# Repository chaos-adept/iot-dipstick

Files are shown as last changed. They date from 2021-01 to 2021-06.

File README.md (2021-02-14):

# IoT Dipstick
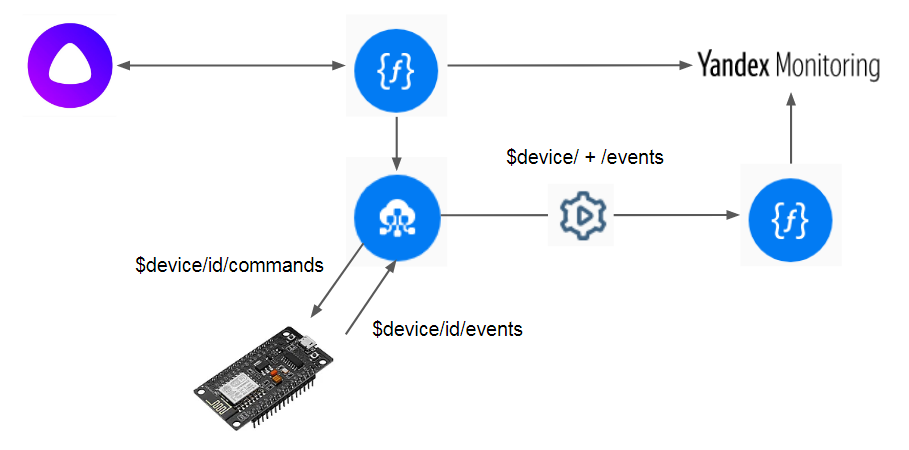
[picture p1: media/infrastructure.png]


### Overview
IoT based on ESP8266 ([NodeMCU v3 board](http://www.nodemcu.com/index_cn.html)) and [Yandex Cloud](https://cloud.yandex.ru/) 
with integration with [Alice](https://yandex.ru/dev/dialogs/alice/doc/about.html)  assistant see [alice-func](terraform/cloud-functions/alice-func)

Alice configuration can't be provided in the source code, you have to configure it on your own. See references in the end of this page.

### Cloud infrastructure provisioning

note to start working with terraform you have to make a `terraform/variables_yc_account.tf`
file with actual values based on the [yandex terraform provider](https://registry.terraform.io/providers/yandex-cloud/yandex/latest/docs)

1. cd `./terraform`
1. make `variables_yc_account.tf` based on [variables_yc_account.tf.sample](terraform/variables_yc_account.tf)
1. `terraform init`
1. `terraform apply`

### Arduino firmware

the firmware is located in `arduino/air-monitor`, it is based on the [Platform IO](https://platformio.org/platformio-ide) as a replacement for Arduino IDE.

#### Initialization
1. create your yandex cloud by the terraform
1. add/modify your wi-fi settings in the `arduino/air-monitor/local_specific_variables.h` 
Once you have initialized your yandex cloud with the terraform scripts `arduino/air-monitor/local_specific_variables.h` 
#### Note
_Cloud infrastructure provisioning_ step generates `arduino/air-monitor/local_specific_variables.h` based on the   
file [arduino/air-monitor/local_specific_variables.h.sample](arduino/experements/air-monitor/local_specific_variables.h.sample)
and your environment settings, for more information see `arduino/scripts/create_local_specific_variables.sh`

### Resources to get started with the project
* [Before to Get Started](../../wiki/Before-to-Get-Started) - List of resources to get required knowledge to work with the project might be found in the wiki page
* [Prehistory and Architecture notes](../../wiki/Prehistory-and-Architecture-notes) - Prehistory of an approach might be found here
* [Alice abilities overview](https://yandex.ru/dev/dialogs/alice/doc/about.html) - Alice abilities development get startred
* [Alice based on the cloud function](https://yandex.ru/dev/dialogs/alice/doc/deploy-ycloud-function.html) - How to integrate [alice-func](terraform/cloud-functions/alice-func) into Alice ability

### IoT Dipstick Prototype
scheme
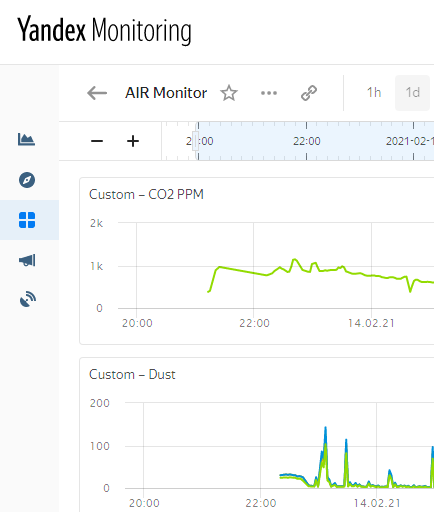
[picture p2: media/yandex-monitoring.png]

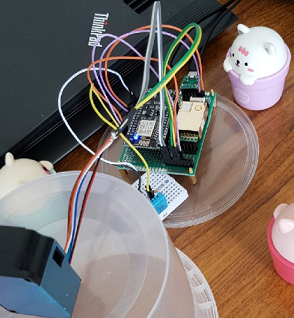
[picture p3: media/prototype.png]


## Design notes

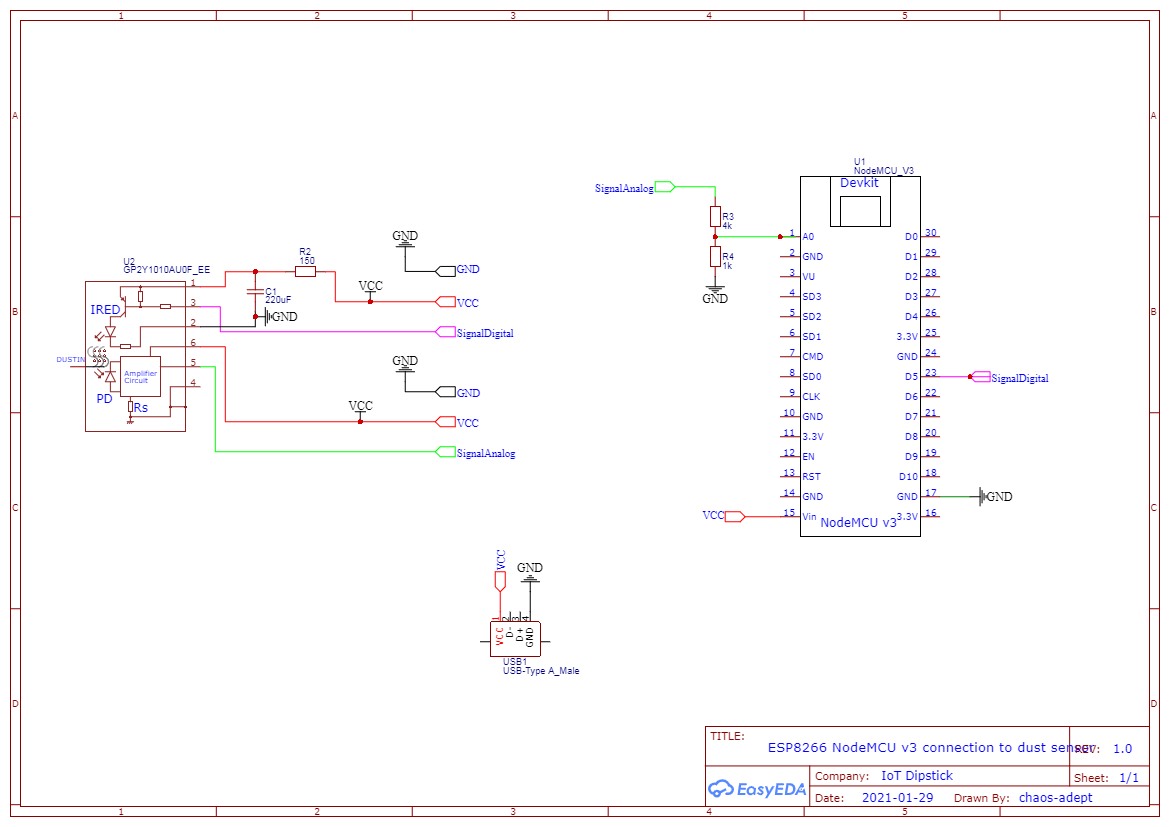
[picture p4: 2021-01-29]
arduino/experements/dust-sensor/GP2Y1010AU0F-no-lib-with-voltage-devider/Schematic_dust-sensor-and-nodemcu_2021-01-29.png

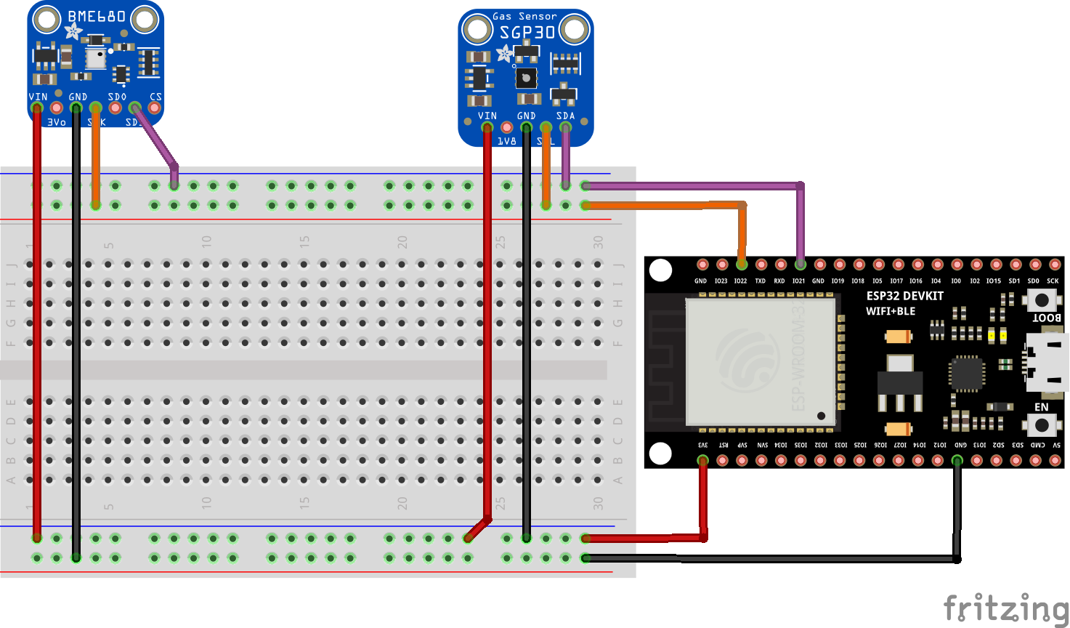
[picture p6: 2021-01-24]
arduino/experements/sensors-sgp30-bme680/fritzing/esp32-bme680-sgp30_bb.png

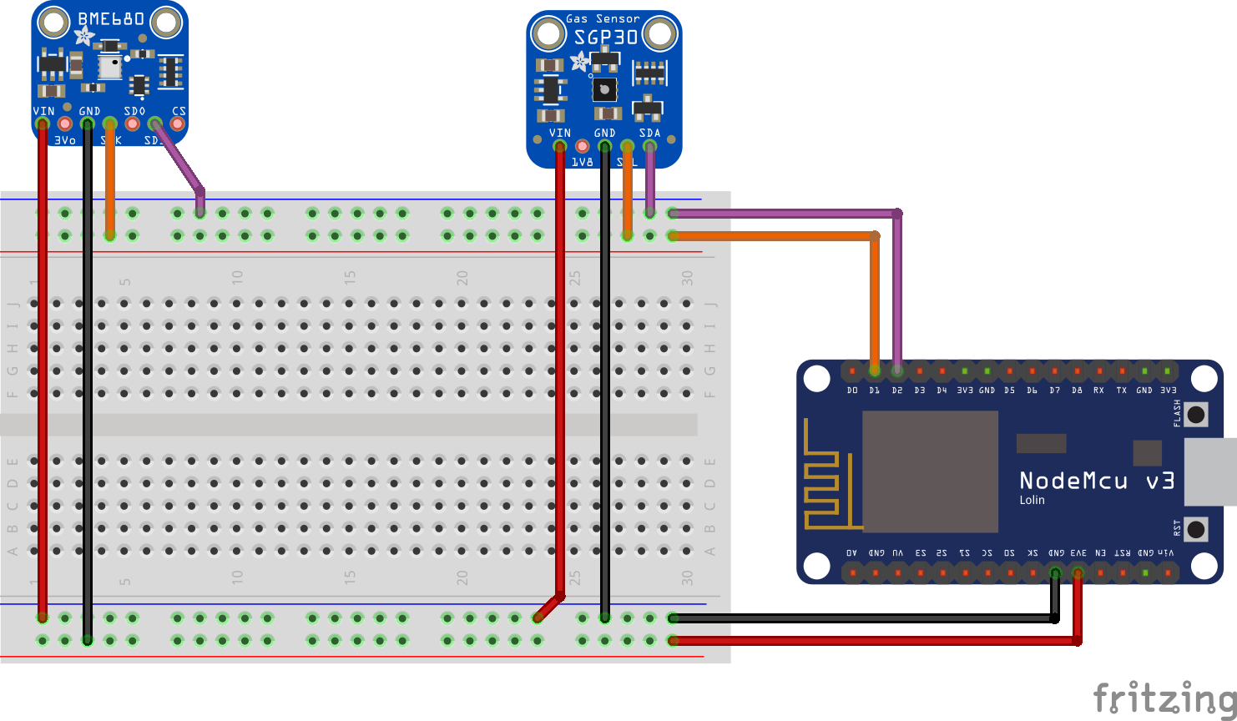
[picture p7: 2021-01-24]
arduino/experements/sensors-sgp30-bme680/fritzing/esp8266-bme680-sgp30_bb.png

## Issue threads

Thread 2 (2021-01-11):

Docs - Provide readme with get started resources

chaos-adept, 2021-01-11:
- [x] provide actual readme with list of community known resources to get started with arduino and esp8266 development
- [x] provide project specific information to get started
- [x] review and close

chaos-adept, 2021-01-13:
point #1 is resolved here
https://github.com/chaos-adept/iot-dipstick/wiki/Before-to-Get-Started

chaos-adept, 2021-01-19:
point 2 has been resolve with the provided readme in the root folder

chaos-adept, 2021-01-20:
review is required

chaos-adept, 2021-01-30:
The review has been done by working with a comrade. He doesn't use doc at all. and It is fine for me.

Closed 2021-01-30.

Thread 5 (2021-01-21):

Device - Check ESP32 as replacement for ESP8266

chaos-adept, 2021-01-21:
- [x] try to send mqtt tls messages to yandex cloud
- [ ] try to read values from dht12
- [ ] make a conditional compilation to include old wifi secure module for esp32

chaos-adept, 2021-01-23:
the result so far esp32 can be used, it was possible to configure it to send message to the cloud and read i2c sensors

chaos-adept, 2021-01-24:
there were several attempts to rewrite code to support conditions in a6ae4475bab39eb1c08531ff91cffdc1faa35624

it doesn't work under arduino ide from the scratch. it seems like an exploration of (esp-idf)[https://docs.espressif.com/projects/esp-idf/en/latest/esp32/] makes sense but it is really time-consuming

chaos-adept, 2021-01-24:
so far this issue is considered as resolved, try attempt was performed for MVP it doesn't make sense to use ESP32 because of difficulties to get started.
1. [esp-idf](https://docs.espressif.com/projects/esp-idf/en/latest/esp32/) exploration is going to be a separate task.
2. esp8266 is considered as the board for MVP

Closed 2021-01-24.

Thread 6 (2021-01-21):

Device - Assembly AIR quality sensors on the board

chaos-adept, 2021-01-21:
- [x] TVOC/eCO2 https://amperkot.ru/msk/catalog/datchik_kachestva_vozduha_v_pomeschenii_sgp30_tvoc_eco2-32614748.html
- [x] Temperature, Pressure and etc - https://amperkot.ru/msk/catalog/datchik_temperaturyi_i_vlazhnosti_bosch_cjmcu680_bme680-39166193.html
- [x] Dust hello world firmware - https://amperkot.ru/msk/catalog/datchik_pyili_sharp_gp2y1010au0f-23869558.html
- [x] Dust Sensor approach with voltage division to adopt 5v out to 1v which is supported by esp8266
- [x] Make a 5v 1a power supply with parallel connection to the esp and dust sensor
- [x] Test dust sensor with 1v out and esp8266
- [x] Integrate dust sensor in the primary firmware

chaos-adept, 2021-01-24:
1. 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
1. 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

results:
1. the first cycle of testing no real values (on esp32)
1. the next cycle of testing zero values (on esp8266, most probably damage on changing wires)

chaos-adept, 2021-01-27:
dust sensor mostly work
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

it should be connected to the esp so far it seems a voltage divider is needed
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

chaos-adept, 2021-01-28:
physical assembly with wemos d1 was successful
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

chaos-adept, 2021-01-29:
added firmware and scheme which is used for ESP8266 NodeMCU v3
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
![Uploading image.png…]()

chaos-adept, 2021-01-30:
this ticket has been resolved dht11 is used instead of dht12 which is really hard to find in the Moscow shops, the new ticket for refactoring firmware will be raised

Closed 2021-01-30.

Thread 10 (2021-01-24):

esp32 usage of esp-idf development

chaos-adept, 2021-01-24:
esp-idf - it is a framework for parallel task execution on the esp32.

this issue derives from #5  "[esp-idf](https://docs.espressif.com/projects/esp-idf/en/latest/esp32/) exploration is going to be a separate task."

it is required to adopt the following functionality under idf based:
* secured mqtt connection to the yandex cloud
* reading data from i2c sensors

chaos-adept, 2021-06-15:
so far it looks that the possible option is incremental migration by step migration to esp32 with dropping support of esp8266 with the usage of FreeRTOS and Arduino libraries + some of esp32 native functions like adc_read_raw, or touch panel

chaos-adept, 2021-06-15:
so far this task can be considered as wont fix

Closed 2021-06-15.

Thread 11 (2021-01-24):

Device - Deep Sleep Support for passive sensor only devices

chaos-adept, 2021-01-24:
Implement firmware for a sensor-only device that sends data with long intervals like 2h.
EPS has the ability to go to deep sleep, it should be used.

note the issue with sending commands to the device which sleep is out of the MVP scope

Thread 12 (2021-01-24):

Terraform - Generate system env variables and arduino header files based on the "apply"

chaos-adept, 2021-01-24:
it is useful to have
* a pre-configured environment for manual testing based `terraform apply`
* ready to use cpp header file with device ids and passwords and with registry id

refer to readme to find where the current firmare header file is located

#18 - related

Closed 2021-02-11.

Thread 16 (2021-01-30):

replace custom implementation of dust sensor wrapper with third party lib

chaos-adept, 2021-01-30:
it derives from #6
there is a bicycle for reading values from dust sensor it should be replaced with third party lib for reducing code base for supporting

chaos-adept, 2021-02-02:
replaced with https://github.com/lixplor/arduino-GP2Y1010AU0F-lib#master

Closed 2021-02-02.

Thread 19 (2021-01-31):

Make a 3d printable constructive model

chaos-adept, 2021-01-31:
models that could be used as the starting points:
* https://www.thingiverse.com/thing:3676533 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
*  https://www.thingiverse.com/thing:2627220 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
* https://www.thingiverse.com/thing:2775946
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

chaos-adept, 2021-02-02:
as a solution for MVP
the "structor" from amperka might be considered as an option https://amperka.ru/collection/structor
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

chaos-adept, 2021-02-02:
considered as closed for now, this time might be used for working with 1w led

chaos-adept, 2021-02-23:
resumed to this work since 2 extra day-offs
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

chaos-adept, 2021-03-06:
the first attempt of printing was unsuccessful, ABS plastic was a reason for deflating models.
the new models under reworking
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

chaos-adept, 2021-03-08:
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
full cover

chaos-adept, 2021-04-18:
the result after the first attempt - 3d model in ABS has been done.
it doesn't assembly well.
it is required too much effort to make a real model with plastic deformation after "freezing".
It makes sense to do another attempt in the PEG or PLA

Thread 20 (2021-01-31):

Find a cheap and applicable CO2/TVOC sensor

chaos-adept, 2021-01-31:
#6 there is an attempt to make the sensor composition.

there are no actual results for CO2 sensor, the [SGP30](https://amperkot.ru/msk/catalog/datchik_kachestva_vozduha_v_pomeschenii_sgp30_tvoc_eco2-32614748.html) was used but it was broken before tests were finished, and it is quite expensive.

chaos-adept, 2021-04-18:
it is not actual, it can be closed as wont fix

Closed 2021-04-18.

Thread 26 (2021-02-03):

Temperature getting doesn't work

chaos-adept, 2021-02-03:
it is not possible to get information from the Alice func, it says that there is no data for the last 3 hours, but it is not correct.

it is a regression bug.

chaos-adept, 2021-02-08:
the issue is not regression, it was presented from the scratch

Closed 2021-02-08.

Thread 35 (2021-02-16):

Explore cucumber for e2e testing

chaos-adept, 2021-02-16:
https://cucumber.io

chaos-adept, 2021-02-17:
the current issue lack of python support  by cucumber , it is required to use nodejs or another framework

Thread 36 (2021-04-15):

PoC flower watering feature

chaos-adept, 2021-04-15:
it is required to assembly autonomy flow watering based
the key abilities:
* measuring soil humidity
* measuring temperature and humidity in the air
* watering
* control of water volume in the tank
* control of water leaks on the floor
* sending monitoring data in the cloud
* working offline
* device sleeping?

chaos-adept, 2021-04-18:
the PoC has been finished with a water pump, bipolar transistor,

* esp8266
* transistor -  https://www.chipdip.ru/product/pn2222a
NPN, Ic=600мА, Vceo=40В, Vcbo=75В, Pd=625мВт, (=2N2222A) [TO-92]
* water pump MI360H4540
* tube with diameter 10mm
* 3x https://supereyes.ru/catalog/Datchiki_arduino/Datchik_vlazhnosti_pochvy_FC_28_c_kontrollerom/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
* ADC/DAC based PCF8591 for reading 3x sensors

chaos-adept, 2021-04-18:
the feature is quite big, it will be a milestone for the development

chaos-adept, 2021-04-18:
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

chaos-adept, 2021-04-18:
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

Closed 2021-04-19.

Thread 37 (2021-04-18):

Feature measue soil humidity

chaos-adept, 2021-04-18:
Background
N Pots with soil with sensors

- [ ]  Scenario: Monitor soil humidity

- [ ]  Scenario: Watering dry soil on schedule

- [ ]  NFR: 1-4 Pots should be supported
- [ ]  NFR: it should have a leak control

chaos-adept, 2021-04-18:
open questions
- [ ] can be i2c bus be placed in non D1, D2 pins
- [ ] pins can be re-ordered without gaps
- [ ] is it enough free pins in the existed firmware? i2c - 2 pins, 0-4 for pump transistors
- [ ] supply 12v and stabilize to 5v over L4940V5 https://www.chipdip.ru/product/l4940v5

chaos-adept, 2021-05-10:
changes from #38 could be taken as a source

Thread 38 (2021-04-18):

Investigate possibility to reuse the single firware for flow watering

chaos-adept, 2021-04-18:
open questions
- [ ] can be i2c bus be placed in non D1, D2 pins
- [ ] pins can be re-ordered without gaps
- [ ] is it enough free pins in the existed firmware? i2c - 2 pins, 0-4 for pump transistors
- [ ] supply 12v and stabilize to 5v over L4940V5 https://www.chipdip.ru/product/l4940v5

chaos-adept, 2021-05-06:
the result so far, the single firmware might be used only if the temperature and humidity sensor will be connected as i2c sensor

as well it is required to apply massive refactoring for message pushing and provide an ability to push messages on-demand from various code components, for example, a water pump can notify that it is opened and that it is closed

it might be a buffer of messages or sending them right away

chaos-adept, 2021-05-10:
so far it makes sense to consider with the issue as resolved with resolution won't fix, devices have really different purposes, so it makes sense to split them and continue work in #37

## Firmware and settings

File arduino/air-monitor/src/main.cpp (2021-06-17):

#define DEBUG true
#define LOGGING_ENABLED true
#define ENABLE_NETWORK_PUBLISH true
#define DEEP_SLEEP true
// #define LOGGING_MEMORY true

#include <debug/common.h>


//uint32_t free = system_get_free_heap_size();
#define uS_TO_MS_FACTOR 1000ULL  /* Conversion factor for micro seconds to mill seconds */
#if !(ESP32)
extern "C" {
    #include "user_interface.h"
}
#include <ESP8266WiFi.h>
#include <NTPClient.h>
#include <PubSubClient.h>  // MQTT Client
#include <WiFiUDP.h>
#else 
#include <Arduino.h>
#include <WiFi.h>
#include <WiFiClientSecure.h>
#include <PubSubClient.h>
// #include <MQTT.h>
#include <ESPmDNS.h>
#include <NTPClient.h>
#endif



// yandex cloud registry settings
#include "yandex_cloud_mqtt_settings.h"

// device specific config should be created by
// './local_specific_variables.h.sample'
#include "format/json_formatter.h"
#include "local_specific_variables.h"
#include "time_utils.h"

#include <power_supply/power_supply.h>

#if (SOIL_MODE)
#include <soil/soil_sensor.h>
#include <water_controller.h>
#elif (SOLAR_MODE)
#else
#include <co2/z19b/z19b_sensor.h>
#include <dht11/dht11_sensor.h>
#include <dust/zh03b/zh03b_sensor.h>
#endif

#define CYCLE_SECONDS 60 * 15
// #define CYCLE_SECONDS 5
#define PUBLISH_INTERVAL (1000 * CYCLE_SECONDS + 1)  // once in the x minutes
#define CYCLE_DELAY (1000 * CYCLE_SECONDS)                  
#define SESNOR_MIN_CLYCLE_DELAY_TO_SLEEP 3000     // sensors will go sleep only if cycle delay more than this value
#define NTP_OFFSET 0                       // In seconds
#define NTP_INTERVAL 60 * 1000             // In miliseconds
#define NTP_ADDRESS "ru.pool.ntp.org"

// PINS
#define CO2_RX_PIN D6
#define CO2_TX_PIN D7
#define DHT_PIN D5
#define DUST_ZH038_RX D2
#define DUST_ZH038_TX D3
#define DUST_GP2Y_ANALOG_IN_PIN D5
#define DUST_GP2Y_LED_CONTROL_PIN A0


// FIXME overlap with the rest sensor pins, it is a reason of SOIL_MODE
// #define SOIL_MODE false
#if SOIL_MODE
#define SOIL_POD_COUNT 1
#define SOIL_ENABLE_WATERING false
#define I2C_PIN_SDA D1
#define I2C_pin_SCL D2
#define SOIL_SENSOR_POWER_CONTROL_PIN D8
#endif

#define DHTTYPE DHT11  // DHT 11


WiFiUDP ntpUDP;
NTPClient timeClient(ntpUDP, NTP_ADDRESS, NTP_OFFSET, NTP_INTERVAL);


typedef void (*Handler)();
typedef MetricCollection (*CollectMetricHandler)();


void updateLedStatus();
Handler updateStateHandlers[] = { updateLedStatus };

MetricResult sensprMetricResultsBuffer[50]; //buffer for sensor metrics, todo move to a class
MetricCollection getSensorMetrics();

#if SOIL_MODE
MetricCollection performWatering();
SoilSensor soilSensor(I2C_PIN_SDA, I2C_pin_SCL, SOIL_POD_COUNT, SOIL_SENSOR_POWER_CONTROL_PIN);
AbstractSensor* sensors[] = {&soilSensor};
int gatePins[] = { D5, D6 };
int gateWaterAmount[] = { 600, 600 }; // important to define otherwise will be water leack
WaterController waterController(SOIL_POD_COUNT, gatePins, gateWaterAmount);
void beginHandler() {
    waterController.begin();
}

Handler beginHandlers[] = {beginHandler};
CollectMetricHandler collecMetricHandlers[] = {getSensorMetrics, performWatering};

#elif SOLAR_MODE

Handler beginHandlers[] = {};
CollectMetricHandler collecMetricHandlers[] = { getSensorMetrics };
PowerVoltageSensor powerVoltageSensor(String("Power Supply Voltage"), ADC1_CHANNEL_0, 4.7f);
PowerVoltageSensor solarVoltageSensor(String("Solar Panel Voltage"), ADC1_CHANNEL_3, 4.7f);
AbstractSensor* sensors[] = { &powerVoltageSensor, &solarVoltageSensor };

#else

Z19BSensor co2sensor(CO2_RX_PIN, CO2_TX_PIN);
DHT11Sensor dth11Sensor(DHT_PIN, DHTTYPE);
ZH03BSensor zh03Sensor(DUST_ZH038_RX, DUST_ZH038_TX);
PowerVoltageSensor powerVoltageSensor(A0);
AbstractSensor* sensors[] = {&co2sensor, &dth11Sensor, &zh03Sensor, &powerVoltageSensor};

Handler beginHandlers[] = {};
CollectMetricHandler collecMetricHandlers[] = {getSensorMetrics};

#endif


const int sensorCount = sizeof(sensors) / sizeof(sensors[0]);

String topicRegistryCommands = String("$registries/") +
                               String(yandexIoTCoreRegistryId) +
                               String("/commands/#");
String topicRegistryCommandLight = String("$registries/") +
                                   String(yandexIoTCoreRegistryId) +
                                   String("/commands/light");
String topicEvents =
    String("$devices/") + String(yandexIoTCoreDeviceId) + String("/events");

boolean needPublish = true;
boolean isSensorsSleeping = true;
bool lightIsOn = true;

unsigned long NONE = 0L;
unsigned long lastLoopStartTime = NONE;
unsigned long currentLoopStartTime = NONE;
unsigned long lastPublishTime = NONE;
//unsigned long timeFromTheLastPublish = PUBLISH_INTERVAL;

WiFiClientSecure net;
PubSubClient client(net);
//BearSSL::X509List x509(registry_root_ca);

void dumpMemory() {
    #ifdef LOGGING_MEMORY
    TRACE("Free memory: ");
    TRACELN(system_get_free_heap_size());
    #endif
}

bool connect() {
    delay(5000);
    TRACE("Conecting to wifi ...");
    int MAX_WIFI_CONNECT_ATTEMPTS = 3;
    int wifiConnectAttempts = 0;
    while (WiFi.status() != WL_CONNECTED) {
        TRACE(".");
        delay(1000);
        wifiConnectAttempts++;
        if (wifiConnectAttempts > MAX_WIFI_CONNECT_ATTEMPTS) {
            TRACELN("Max Wi-Fi connection attempts were reached.");
            return false;
        }
    }
    TRACELN(" Connected");
    net.setInsecure();
    //net.setCACert(registry_root_ca);
    TRACE("Connecting to Yandex IoT Core as");
    TRACE(yandexIoTCoreDeviceId);
    TRACE(" ...");
    while (!client.connect("Esp8266Client", yandexIoTCoreDeviceId,
                           yandexIoTCoreDevicePassword)) {
        TRACE(".");
        delay(1000);
    }
    TRACELN(" Connected");

    TRACELN("registry command topic:");
    TRACELN(topicRegistryCommands);

    boolean subcribed = client.subscribe(topicRegistryCommands.c_str());
    TRACELN(subcribed);

    return true;
}

void messageReceived(char* topic, byte* payload, unsigned int length) {
    String topicString = String(topic);
    TRACE("Message received. Topic: ");
    TRACELN(topicString.c_str());
    String payloadStr = "";
    for (unsigned int i = 0; i < length; i++) {
        payloadStr += (char)payload[i];
    }
    TRACE("Payload: ");
    TRACELN(payloadStr);

    if (topicRegistryCommandLight == topicString) {
        TRACE("Handling light cmd");
        lightIsOn = payloadStr.equals("True");
        TRACELN(lightIsOn);

        digitalWrite(LED_BUILTIN, lightIsOn ? LOW : HIGH);
    } else {
        TRACELN("Unknown command");
    }
}

void setup() {
    pinMode(LED_BUILTIN, OUTPUT);
    #if !ESP32
    pinMode(D0, WAKEUP_PULLUP);
    #endif

    for (int i = 0; i < sizeof(beginHandlers)/sizeof(Handler); i++) {
        beginHandlers[i]();
    }

    digitalWrite(LED_BUILTIN, LOW);

    delay(1000);

    DEBUG_SERIAL.setTimeout(2000);
    DEBUG_SERIAL.begin(DEBUG_SERIAL_BAUDRATE);
    
    dumpMemory();

    delay(10);
    TRACELN("Device started");
    TRACE("Sensor count: ");
    TRACELN(sensorCount);
    
    WiFi.begin(ssid, password);
    client.setServer(mqttserver, mqttport);
    client.setCallback(messageReceived);
    client.setBufferSize(mqttBufferSize);
    client.setKeepAlive(mqttKeepAlive / 1000);

    timeClient.begin();

    digitalWrite(LED_BUILTIN, HIGH);

    for (int indx = 0; indx < sensorCount; indx++) {
        sensors[indx]->begin();
    }
    
    delay(3000);
}

boolean publishMetrics(MetricCollection metricCollection) {

    if (metricCollection.count < 1) {
        TRACELN("no metrics to send data");
        return false;
    }

    if (lightIsOn) {
        digitalWrite(LED_BUILTIN, HIGH);
        delay(10);
        digitalWrite(LED_BUILTIN, LOW);
    }

    char* msg = threadUnsafeFormatMetricsAsJson(timeClient.getEpochTime(),
                                                metricCollection.results, metricCollection.count);
    TRACELN(msg);

    #if ENABLE_NETWORK_PUBLISH
    if (client.publish(topicEvents.c_str(), msg)) {
        TRACELN(topicEvents);
        TRACELN("Publish ok");
        return true;
    } else {
        TRACELN("Publish failed");
        return false;
    }
    #else
        return true;
    #endif
}

MetricCollection getSensorMetrics() {
   // get alive sensors
    int aliveSensorCount = 0;
    int totalExpectedMetricCount = 0;
    AbstractSensor* aliveSensors[sensorCount];
    for (int indx = 0; indx < sensorCount; indx++) {
        AbstractSensor* sensor = sensors[indx];
        if (sensor->isAlive()) {
            aliveSensors[aliveSensorCount] = sensor;
            aliveSensorCount++;
            totalExpectedMetricCount += sensor->getMetricsCount();
        }
    }

    if (aliveSensorCount == 0) {
        return { NULL, 0 };
    } else {
        
        // results might be more than sensors
        
        MetricResult* results = sensprMetricResultsBuffer;  
        int resultMetricsCount = 0;
        for (int sensorIndx = 0; sensorIndx < aliveSensorCount; sensorIndx++) {
            AbstractSensor* sensor = aliveSensors[sensorIndx];
            MetricResult* metrics = sensor->getMetrics();
            for (int metricIndx = 0; metricIndx < sensor->getMetricsCount(); metricIndx++) {
                results[resultMetricsCount] = metrics[metricIndx];
                resultMetricsCount++;
            }
        }

        return { results, totalExpectedMetricCount };
    }    
}

void updateLedStatus() {
    // Turn the LED on by making the voltage LOW
    if (lightIsOn) {
        digitalWrite(LED_BUILTIN, LOW);
    } else {
        digitalWrite(LED_BUILTIN, HIGH);
    }
}


#if SOIL_MODE

MetricCollection performWatering() {
    #if SOIL_ENABLE_WATERING
    waterController.performWateringIfNeeded(soilSensor.getMetrics());
    return { waterController.getMetrics(), waterController.getPotsCount() };
    #else
    TRACELN("watering is disabled");
    return { NULL, 0 };
    #endif
}

#endif

void updateControllerState() {
    updateLedStatus(); //fixme it needs to be moved to the update state/render state section

    unsigned long timeFromTheLastPublish = millis() - lastPublishTime;
    needPublish = (PUBLISH_INTERVAL <= (timeFromTheLastPublish)) || (lastPublishTime == NONE);


    int metricCollectionCount = sizeof(collecMetricHandlers) / sizeof(CollectMetricHandler);

    MetricCollection metricCollections[metricCollectionCount];

    for (int i = 0; i < metricCollectionCount; i++) {
        metricCollections[i] = collecMetricHandlers[i]();
    }


    #if ENABLE_NETWORK_PUBLISH
    TRACELN("next cycle, time from last publish: " +
                        String(timeFromTheLastPublish));
    
    if (needPublish) {
        client.loop();

        bool hasConnected = client.connected() || connect();;
        if (!hasConnected) {
            TRACELN("Device can't connect to the network.");
        }

        TRACELN("Metric publishing is skipped needPublish:" + String(needPublish) + " hasConnected:" + String(hasConnected));

        timeClient.update();

        dumpMemory();

        //push metrics
        if (needPublish && hasConnected) { //fixme it needs to be moved to the update state/render state section
            boolean published = true;

            for (int i = 0; i < metricCollectionCount; i++) {
                published = publishMetrics(metricCollections[i]) && published;
            }

            if (published) {
                lastPublishTime = millis();
            } else {
                TRACELN("There are issues during the publishing metrcs, last time publish is not updated");
            }
        }
    }
    #else
    TRACELN("publishing metrics are disabled");
    #endif
}

void loop() {
    dumpMemory();
    currentLoopStartTime = millis();
    

    if (isSensorsSleeping) {
        for (int indx = 0; indx < sensorCount; indx++) {
            sensors[indx]->wakeup();
        }      
        isSensorsSleeping = false;  
    }

    dumpMemory();

    for (int indx = 0; indx < sensorCount; indx++) {
        sensors[indx]->onLoopCycle(); 
    }

    dumpMemory();

    updateControllerState();

    dumpMemory();
    
    for (int indx = 0; indx < sensorCount; indx++) {
        sensors[indx]->onDataClean();
    }

    unsigned long loopEndTime = millis();

    TRACE("sleep for ");
    TRACE(CYCLE_DELAY);
    TRACE(" cycle actual time ");
    unsigned long delta = (loopEndTime - currentLoopStartTime);
    
    TRACE(delta);
    if (delta > CYCLE_DELAY) {
        TRACELN(", Cycle time more than expected - skip cycle delay.");
        lastLoopStartTime = currentLoopStartTime;
        return;
    }

    TRACE(" actualDelay ");
    unsigned long actualDelay = CYCLE_DELAY - delta;
    TRACELN(actualDelay);

    dumpMemory();

    //turn sensors in the sleep mode
    if (actualDelay > SESNOR_MIN_CLYCLE_DELAY_TO_SLEEP) {
        for (int indx = 0; indx < sensorCount; indx++) {
            sensors[indx]->sleep();
        }
        isSensorsSleeping = true;
    }

    lastLoopStartTime = currentLoopStartTime;

    dumpMemory();
    
        if (DEEP_SLEEP) {
            TRACELN("DEEP sleep enabled go to deep sleep");
            uint64_t deepSleepTime = actualDelay * uS_TO_MS_FACTOR;
#if !ESP32
            uint64_t maxDeepSleep = ESP.deepSleepMax();
            long deepSleepInHours = (ESP.deepSleepMax() / 1000 / 1000 / 60 / 60);
            TRACEVALN("Max deep sleep in hours", deepSleepInHours);

            if (deepSleepTime > maxDeepSleep)
            {
                deepSleepTime = ESP.deepSleepMax();
                TRACELN("truced to deep sleep");
            }

            ESP.deepSleep(deepSleepTime, RF_DEFAULT);
#else
            int deepSleepResult = esp_sleep_enable_timer_wakeup(deepSleepTime);
            if (deepSleepResult != ESP_OK) {
                TRACEVALN("error during go sleep", deepSleepResult);
            }
            esp_deep_sleep_start();
#endif
        } else {
            delay(actualDelay);
        }

}

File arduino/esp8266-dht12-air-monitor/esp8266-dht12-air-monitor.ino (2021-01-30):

#include <DHT12.h>
#include <NTPClient.h>
#include <ESP8266WiFi.h>
#include <WiFiUDP.h>
#include <PubSubClient.h> // MQTT Client

// yandex cloud registry settings
#include "yandex_cloud_mqtt_settings.h"

// device specific config should be created by './local_specific_variables.h.sample'
#include "local_specific_variables.h"
#include "time_utils.h"

// note we should avoid reaching max mqttKeepAlive time, it is a reason why it is reduced twice
#define PUBLISH_TIMEOUT 1000 * mqttKeepAlive/2

#define NTP_OFFSET   0      // In seconds
#define NTP_INTERVAL 60 * 1000    // In miliseconds
#define NTP_ADDRESS  "ru.pool.ntp.org"
#define DEBUG_SERIAL Serial
#define DEBUG_SERIAL_BAUDRATE 115200

WiFiUDP ntpUDP;
NTPClient timeClient(ntpUDP, NTP_ADDRESS, NTP_OFFSET, NTP_INTERVAL);

DHT12 dht12;

char msg[400];
const char* msgTemplate = "{\"TimeStamp\":\"%s\",\n \"Values\":\n[{\"Type\":\"Float\",\"Name\":\"Humidity\",\"Value\":null},\n {\"Type\":\"Float\",\"Name\":\"CarbonDioxide\",\"Value\":null},\n {\"Type\":\"Float\",\"Name\":\"Pressure\",\"Value\":null},\n {\"Type\":\"Float\",\"Name\":\"Temperature\",\"Value\":\"%d.%02d\"}]}";
String topicRegistryCommands = String("$registries/")+String(yandexIoTCoreRegistryId)+String("/commands/#");
String topicRegistryCommandLight = String("$registries/")+String(yandexIoTCoreRegistryId)+String("/commands/light");
String topicEvents = String("$devices/")+String(yandexIoTCoreDeviceId)+String("/events");

boolean needPublish = false;
bool lightIsOn = false;

WiFiClientSecure  net;
PubSubClient client(net);
BearSSL::X509List x509(registry_root_ca);

void connect() {
  delay(5000);
  DEBUG_SERIAL.print("Conecting to wifi ...");
  while (WiFi.status() != WL_CONNECTED) {
    DEBUG_SERIAL.print(".");
    delay(1000);
  }
  DEBUG_SERIAL.println(" Connected");
  net.setInsecure();
  DEBUG_SERIAL.print("Connecting to Yandex IoT Core as");
  DEBUG_SERIAL.print(yandexIoTCoreDeviceId);
  DEBUG_SERIAL.print(" ...");
  while (!client.connect("Esp8266Client", yandexIoTCoreDeviceId, yandexIoTCoreDevicePassword)) {
    DEBUG_SERIAL.print(".");
    delay(1000);
  }
  DEBUG_SERIAL.println(" Connected");
  
  DEBUG_SERIAL.println("registry command topic:");
  DEBUG_SERIAL.println(topicRegistryCommands);

  boolean subcribed = client.subscribe(topicRegistryCommands.c_str());
  DEBUG_SERIAL.println(subcribed);
}

void setup() {

  pinMode(LED_BUILTIN, OUTPUT);
  DEBUG_SERIAL.setTimeout(2000);
  DEBUG_SERIAL.begin(DEBUG_SERIAL_BAUDRATE);
  delay(10);
  DEBUG_SERIAL.println("Device started");
  WiFi.begin(ssid, password);
  client.setServer(mqttserver, mqttport);
  client.setCallback(messageReceived);
  client.setBufferSize(mqttBufferSize);
  client.setKeepAlive(mqttKeepAlive);

  timeClient.begin();
  dht12.begin();

  digitalWrite(LED_BUILTIN, HIGH);
}

void messageReceived(char* topic, byte* payload, unsigned int length) {
  String topicString = String(topic);
  DEBUG_SERIAL.print("Message received. Topic: ");
  DEBUG_SERIAL.println(topicString.c_str());
  String payloadStr = "";
  for (int i=0;i<length;i++) {
    payloadStr += (char)payload[i];
  }
  DEBUG_SERIAL.print("Payload: ");
  DEBUG_SERIAL.println(payloadStr);

  if (topicRegistryCommandLight == topicString) {
    DEBUG_SERIAL.print("Handling light cmd");
    lightIsOn = payloadStr.equals("True");
    DEBUG_SERIAL.println(lightIsOn);
    digitalWrite(LED_BUILTIN, lightIsOn ? LOW : HIGH);
  } else {
    DEBUG_SERIAL.println("Unknown command");
  }

}

void loop() {

  DEBUG_SERIAL.println("next cycle");
  
  client.loop();

  if (!client.connected()) {
    connect();
  }

  // Turn the LED on by making the voltage LOW
  if (lightIsOn) {
    digitalWrite(LED_BUILTIN, LOW); 
  } else {
    digitalWrite(LED_BUILTIN, HIGH); 
  }

  if(needPublish) {
    if (lightIsOn) {
      digitalWrite(LED_BUILTIN, HIGH);
      delay(10);
      digitalWrite(LED_BUILTIN, LOW);
    }

    DHT12::ReadStatus chk = dht12.readStatus();
    switch (chk) {
    case DHT12::OK:
      break;
    case DHT12::ERROR_CHECKSUM:
      Serial.println(F("Checksum error"));
      break;
    case DHT12::ERROR_TIMEOUT:
      Serial.println(F("Timeout error"));
      break;
    case DHT12::ERROR_TIMEOUT_LOW:
      Serial.println(F("Timeout error on low signal, try put high pullup resistance"));
      break;
    case DHT12::ERROR_TIMEOUT_HIGH:
      Serial.println(F("Timeout error on low signal, try put low pullup resistance"));
      break;
    case DHT12::ERROR_CONNECT:
      Serial.println(F("Connect error"));
      break;
    case DHT12::ERROR_ACK_L:
      Serial.println(F("AckL error"));
      break;
    case DHT12::ERROR_ACK_H:
      Serial.println(F("AckH error"));
      break;
    case DHT12::ERROR_UNKNOWN:
      Serial.println(F("Unknown error DETECTED"));
      break;
    case DHT12::NONE:
      Serial.println(F("No result"));
      break;
    default:
      Serial.println(F("Unknown error"));
      break;
    }
    
    // Read temperature as Celsius (the default)
    float t12 = dht12.readTemperature();
    // Read temperature as Fahrenheit (isFahrenheit = true)
    float f12 = dht12.readTemperature(true);
    // Sensor readings may also be up to 2 seconds 'old' (its a very slow sensor)
    float h12 = dht12.readHumidity();

    bool dht12Read = true;
    // Check if any reads failed and exit early (to try again).

    if (isnan(h12) || isnan(t12) || isnan(f12)) {
      Serial.println("Failed to read from DHT12 sensor!");

      dht12Read = false;
    }

    if (dht12Read){
      // Compute heat index in Fahrenheit (the default)
      float hif12 = dht12.computeHeatIndex(f12, h12);
      // Compute heat index in Celsius (isFahreheit = false)
      float hic12 = dht12.computeHeatIndex(t12, h12, false);
      // Compute dew point in Fahrenheit (the default)
      float dpf12 = dht12.dewPoint(f12, h12);
      // Compute dew point in Celsius (isFahreheit = false)
      float dpc12 = dht12.dewPoint(t12, h12, false);

      timeClient.update();
      String formattedTime = getFormattedDate(timeClient.getEpochTime());

      snprintf(msg, sizeof(msg), msgTemplate,
        formattedTime.c_str(),
        (int)t12, (int)(t12*100)%100   
      );

      DEBUG_SERIAL.println(msg);
      
      if (client.publish(topicEvents.c_str(), msg)) {        
          DEBUG_SERIAL.println(topicEvents);
          DEBUG_SERIAL.println("Publish ok");
      } else {
        DEBUG_SERIAL.println("Publish failed");
      }

    }
  }

  DEBUG_SERIAL.print("sleep for ");
  DEBUG_SERIAL.println(PUBLISH_TIMEOUT);
  delay(PUBLISH_TIMEOUT);
}

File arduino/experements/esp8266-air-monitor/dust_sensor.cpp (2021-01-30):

#include <Arduino.h>

float afterDividedMaxVoltage = 1;
float realOriginalSensorVoltage = 5;

int measurePin = A0;
int ledPower = D5;

unsigned int samplingTime = 280;
unsigned int deltaTime = 40;
unsigned int sleepTime = 10;

float voMeasured = 0;
float calcVoltage = 0;
float voRawVoltage = 0;
float dustDensity = 0;

#ifdef ESP8266
float analogPinVoltMaxRange = 3.3; //tested on wemos d1 r2, nodemcu v3
#else
float analogPinVoltMaxRange = 5;
#endif  

void setupDustSensor() {
  pinMode(ledPower,OUTPUT);
}

float measureDustSensorValue() {
  digitalWrite(ledPower, LOW);
  delayMicroseconds(samplingTime);

  voMeasured = analogRead(measurePin);

  delayMicroseconds(deltaTime);
  digitalWrite(ledPower, HIGH);
  delayMicroseconds(sleepTime);

  voRawVoltage = voMeasured * (analogPinVoltMaxRange/1024);
  calcVoltage = (voRawVoltage * realOriginalSensorVoltage/afterDividedMaxVoltage);
  dustDensity = 0.17*calcVoltage-0.1;

  if ( dustDensity < 0)
  {
    dustDensity = 0.00;
  }

  return dustDensity;
}

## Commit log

2021-01-20 fixed broken link to the arduino local variables
2021-01-24 added sensor tester firware and fritzing sources
    [esp32-bme680-sgp30.fzz, esp8266-bme680-sgp30.fzz]
2021-01-24 added dust sensor samples for v5 board / additional work for esp8266 / issue #6
    [GP2Y1010AU0F-no-lib.ino, GP2Y1010AU0F.ino]
2021-01-24 samples for supporting debugging sending command from Alice to devices
2021-01-28 added arduino samples for wemos d1 r2 #6
2021-01-29 fix(# 4 Cloud Functions - fix sending commands on the devices): fix device id in terraform, add tests for sentLight func
2021-01-29 fix(# 4 Cloud Functions - fix sending commands on the devices): update unit test, fix topic
2021-01-29 fixes in the firmware, replaced with registry topic / not finished #4
    [esp8266-dht12-air-monitor.ino]
2021-01-30 fixes for handling messages for iot registry without timeout, add separation to the special command 'light' #4
    [esp8266-dht12-air-monitor.ino]
2021-01-30 simpliest integrated with dust sensor #6
2021-01-30 simpliest integrated with dust sensor / added missed files #6
    [dust_sensor.cpp]
2021-01-30 refactored for usage dust sensor and refactored to use dht11 instead of dht12 #6
2021-01-31 primary arduino firmware has been migrated to the platform.io #18
    [esp32-bme680-sgp30.fzz, esp8266-bme680-sgp30.fzz]
2021-01-31 #16 migration to the dust sensor lib
2021-02-02 fixed issue with wrong pin, reworked sending by interval #7
    [dust_sensor.cpp, main.cpp]
2021-02-02 code has been reworked, library used loop time calc optimized, avg dust value is used #16
    [dust_sensor.cpp, main.cpp]
2021-02-02 fixed issue with cycle delay #16
    [main.cpp]
2021-02-08 cosmetic fixes, enabling logger variable parting, getting weather from multiple devices in Alice function #7 #26
2021-02-09 refactored for adding abstract sensor / not finished #29
2021-02-10 feat(feature/#12-system-envs): - set environment variables on apply and reset on destroy actions - output cloud function identifiers - use in publish-from-registry-to-device-commands.sh and subscribe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
2021-02-10 feat(feature/#12-system-envs):
    add placeholders to local_specific_variables.h.sample
    impl create_local_specific_variables.sh to generate
    local_specific_variables.h file
    Closes #12
2021-02-13 massive refactoring has been applied to the firmware, custom sensors are supported, multiple values from sensor is pending, z19b sesnsor is supported now #29 #28
2021-02-13 added multiple metrics from the one sensor #29
2021-02-13 fixed dht11 humidity values, and metric names #29
    [main.cpp]
2021-02-13 attempt to integrate zh03b, it works over arduino ide example but doesn't work in the firmware #27
    [ZH03Bsensor.ino]
2021-02-13 fixed issue with wrong pm10 calculation #27
    [main.cpp]
2021-02-14 added photos to readme
    [zh03b_demo2.csv]
2021-02-14 fixed link to the prototype in the readme
2021-04-18 PoC for flower watering #36
2021-04-21 fixes in the terraform and unit testing before adding flower watering feature, ref #38
    [main.cpp, test_main.cpp]
2021-04-24 added a workaround for measuring under unit tests # #38
    [test_main.cpp]
2021-04-27 sensor added into main firmware #38
2021-04-27 cosmetic refactoring moving dht11 to pin d5 #38
2021-05-06 controlling two pumps and separation based on directives, massive refactoring needed #38
2021-05-16 cosmetic fixes for recovering supporting of original non-watering functionality #38
    [main.cpp, test_main.cpp]
2021-06-06 before migration to esp32
2021-06-15 added basic esp32 support #37
2021-06-15 cosmetic changes in voltage sensor
2021-06-15 added usage of adc channels #40
2021-06-17 added voltage measuring with divider #40
